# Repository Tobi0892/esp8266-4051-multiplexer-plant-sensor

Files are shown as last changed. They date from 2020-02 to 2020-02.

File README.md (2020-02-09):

# ESP8266 Multi Capacitive Soil Moisture Sensor

ESP8266 in combination with a eight port multiplexer to **support up to 8 capacitive soil moisture sensors**.

The esp8266 reads the sensors every 10 minutes, transfers the readings via MQTT to a broker and goes back to deep sleep. The MQTT messages and can be picked up by i.e. Home Assistant.

- Mode 1: USB powered
- Mode 2: Battery powered (optional solar)

The code is written in **MicroPython**.

## Mode 1: USB powered

### Parts required

- [Wemos D1 mini Pro V2.0.0 ESP8266](https://www.aliexpress.com/item/32724692514.html) 4,56€
- [Capacitive soil moisture sensor](https://www.aliexpress.com/item/32863717622.html) 0,61€
- [CD4051 Multiplexer](https://www.aliexpress.com/item/32424603555.html) 1,85€
- [Project box](https://www.aliexpress.com/item/4000392100897.html) 0,72€
- [Circuit board](https://www.aliexpress.com/item/1848518580.html) 1,66€
- [Wires](https://www.aliexpress.com/item/4000329909050.html) 1,90€
- [Pin headers](https://www.aliexpress.com/item/32861400498.html) 0,88€
- [3D printed sensor case](https://www.thingiverse.com/thing:2806217) (order print at [treatstock](https://www.treatstock.com/c/gregtu)) ~1,20€

A usb charger and micro usb cable is assumed to be available.

### Circuit diagram

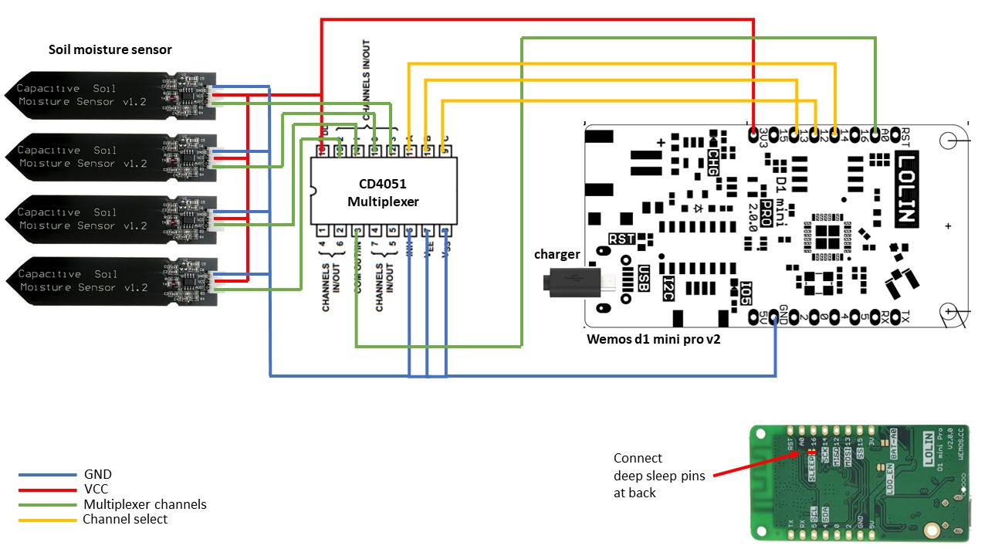
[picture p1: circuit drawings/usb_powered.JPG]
mode 1 wiring


## Mode 2: Battery powered

Use more batteries in parallel if you want (a) to decrease the time between sensor readings or (b) prolong the time until the next charging cycle or (c) compensate for smaller solar panels.

The solar panel is optional, of course you can also charge the batteries manually with a charger once they are drained. If you use a solar panel, you need to connect it via the micro usb port to the esp8266

Note: the Wemos D1 mini Pro v2.0.0 already has a built-in charging module. 

### Additional parts required

- [18650 3,7V 3400mAh battery](https://www.aliexpress.com/item/33016517000.html) 2,21€
- [JST connector](https://www.aliexpress.com/item/33027366342.html) 0,49€
- [Optinal 5V 5W solar panel](https://www.aliexpress.com/item/32952130996.html) 4,13€

### Circuit diagram

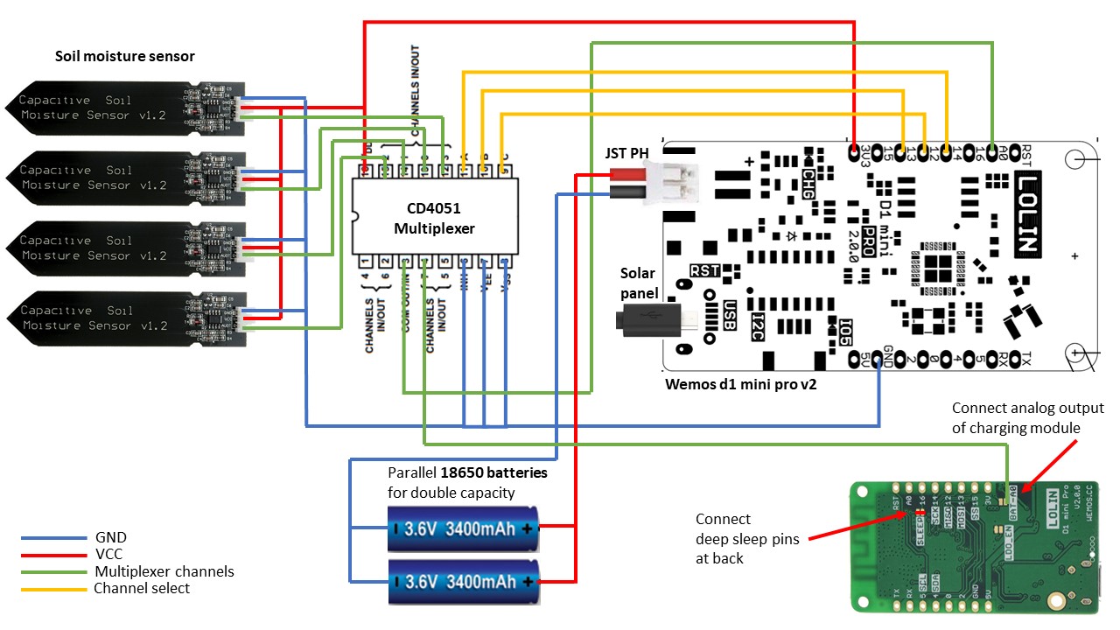
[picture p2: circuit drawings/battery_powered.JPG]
mode 2 wiring


## Setup

### Configuration

Use the `config.json` to configure the esp8266 (no changes in `boot.py` or `main.py` required).

```json
{
  "hostname": "NAME_OF_ESP8266",
  "wifi": {
    "ssid": "YOUR_WIFI_NAME",
    "password": "YOUR_WIFI_PASSWORD",
  },
  "mqtt": {
    "user": "MQTT_USER",
    "password": "MQTT_PASSWORD",
    "broker": "MQTT_BROKER_IP",
    "port": 1883,
    "topics": "TOPIC_NAME"
  }
}
```

### Flashing Code to ESP8266

I prefer PyCharm and the respective [MicroPython plugin](https://blog.jetbrains.com/pycharm/2018/01/micropython-plugin-for-pycharm/). Nevertheless, you can use any other suitable editor.

Create a configuration for each of the three files and flash them onto the esp8266. You can use the MicroPython REPL to watch the execution of the programs:

```
Connecting to WiFi...connected
Connecting to MQTT...connected
Sending: {"analog": "481", "percent": "7", "updated": "07.02.2020 23:12:25"} 
Going back to sleep...
```

### Home Assistant

Add i.e. two mqtt sensors to your `sensors.yaml` (your one esp8266 published to both topics as it operates multiple soil moisture sensors)

```yaml
- platform: mqtt
  name: "Ficus Benjamina"
  state_topic: "esp8266/pflanzen-wohnzimmer-fenster/sensor0"
  value_template: "{{ value_json.percent }}"
  unit_of_measurement: "%"
  json_attributes_topic: "esp8266/pflanzen-wohnzimmer-fenster/sensor0"
  icon: mdi:leaf
- platform: mqtt
  name: "Zitronenbaum"
  state_topic: "esp8266/pflanzen-wohnzimmer-fenster/sensor1"
  value_template: "{{ value_json.percent }}"
  unit_of_measurement: "%"
  json_attributes_topic: "esp8266/pflanzen-wohnzimmer-fenster/sensor1"
  icon: mdi:fruit-citrus
- platform: mqtt
  name: "Balsamapfel"
  state_topic: "esp8266/pflanzen-wohnzimmer-fenster/sensor2"
  value_template: "{{ value_json.percent }}"
  unit_of_measurement: "%"
  json_attributes_topic: "esp8266/pflanzen-wohnzimmer-fenster/sensor2"
  icon: mdi:sprout
```

And the following to `ui-lovelace.yaml` to display the two sensors in the lovelace frontend ([Custom multiple entities card is used in this example](https://github.com/benct/lovelace-multiple-entity-row))

```yaml
  - type: markdown
    style: !include /config/ui-lovelace/style/title.yaml
    content: Pflanzen

  - type: entities
    entities:
      - type: custom:multiple-entity-row
        entity: sensor.ficus_benjamina
        hide_state: true
        primary:
          entity: sensor.ficus_benjamina
          attribute: analog
          unit: ''
          name: 'Analog'
        secondary:
          entity: sensor.ficus_benjamina
          attribute: percent
          name: 'Wasser'
          unit: '%'
      - entity: sensor.zitronenbaum
        hide_state: true
        type: custom:multiple-entity-row
        primary:
          entity: sensor.zitronenbaum
          attribute: analog
          unit: ''
          name: 'Analog'
        secondary:
          entity: sensor.zitronenbaum
          attribute: percent
          unit: '%'
          name: 'Wasser'
      - entity: sensor.balsamapfel
        hide_state: true
        type: custom:multiple-entity-row
        primary:
          entity: sensor.balsamapfel
          attribute: analog
          unit: ''
          name: 'Analog'
        secondary:
          entity: sensor.balsamapfel
          attribute: percent
          unit: '%'
          name: 'Wasser'
```

Result in lovelace frontend:

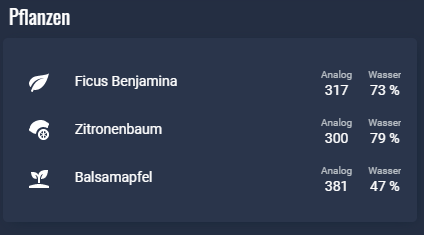
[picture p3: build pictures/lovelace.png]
lovelace


Detail view:

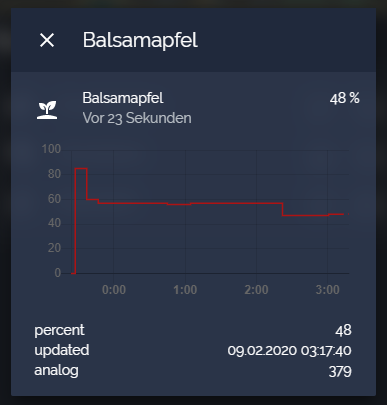
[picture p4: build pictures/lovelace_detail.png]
lovelace_details


## Schematics

- [Wemos D1 mini pro](https://wiki.wemos.cc/products:d1:d1_mini_pro)
- [CD4051 Multiplexer](http://www.ti.com/lit/ds/schs047i/schs047i.pdf)

## Build pictures
Two sensors placed in a plant each
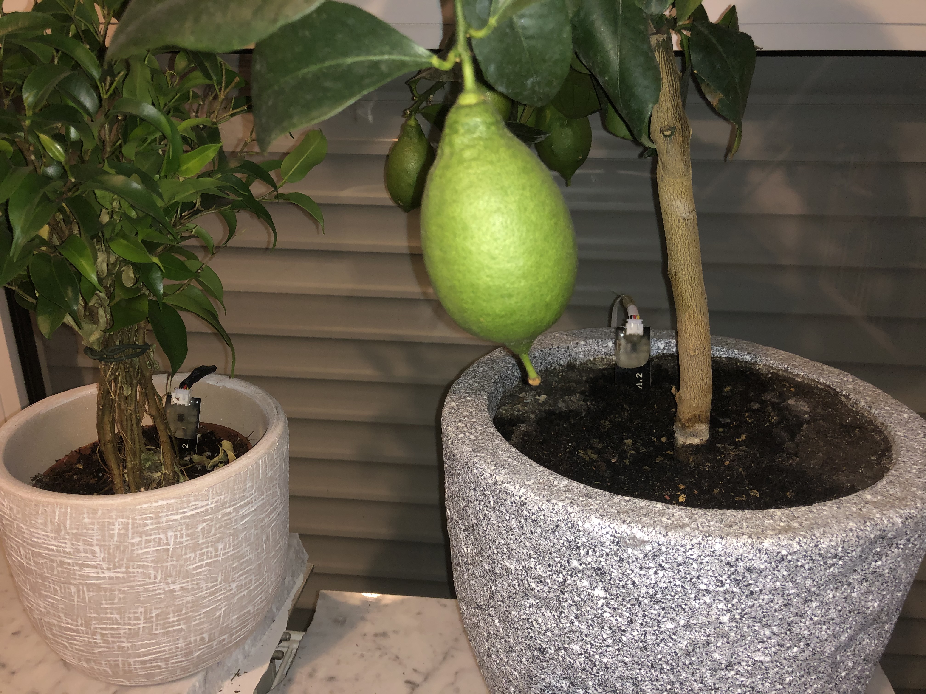
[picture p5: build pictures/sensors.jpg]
sensors


Indoor case ([source](https://www.thingiverse.com/thing:2806217))
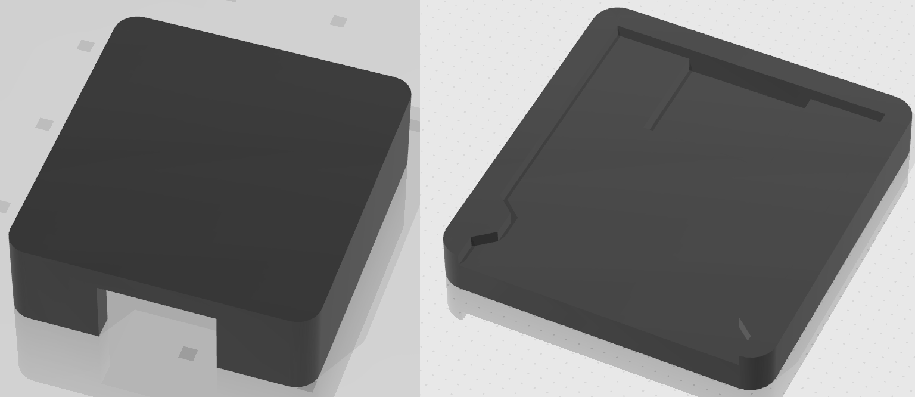
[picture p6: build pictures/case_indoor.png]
indoor_case


Outdoor case with top cover ([source](https://www.thingiverse.com/thing:3625073))
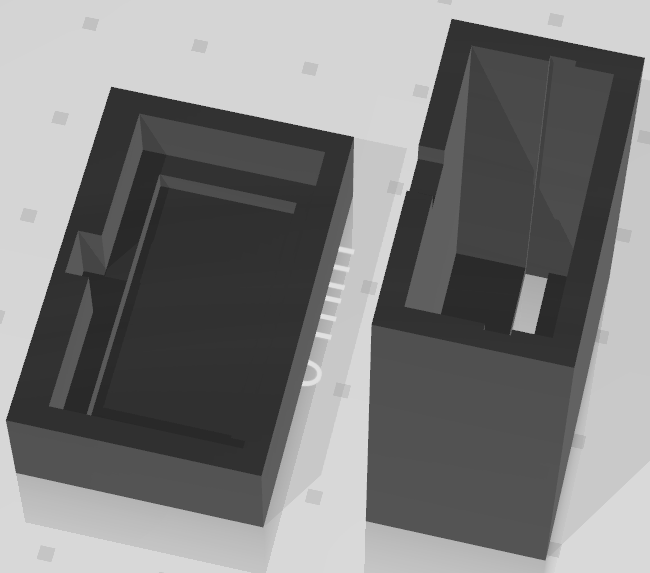
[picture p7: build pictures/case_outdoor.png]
outdoor_case


Three sensors connected to the esp (3 more available - multiplexer supports up to 8)
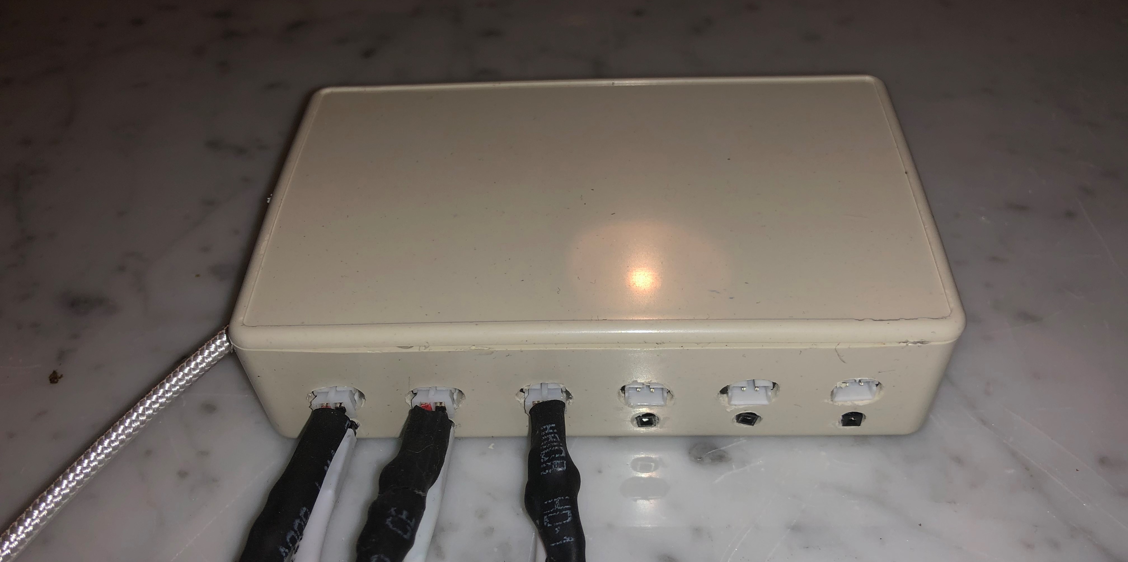
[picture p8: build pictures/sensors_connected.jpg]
sensors_connected


Front view of the connectors (the wholes could have been drilled better)
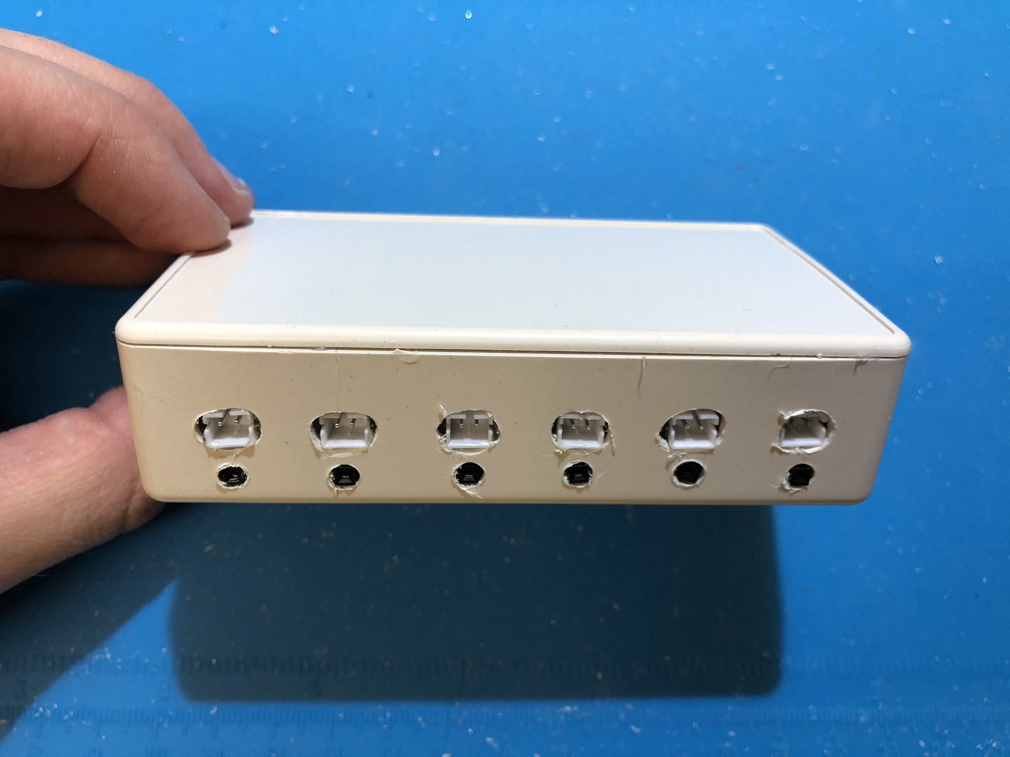
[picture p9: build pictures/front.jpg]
front


Micro usb power connected
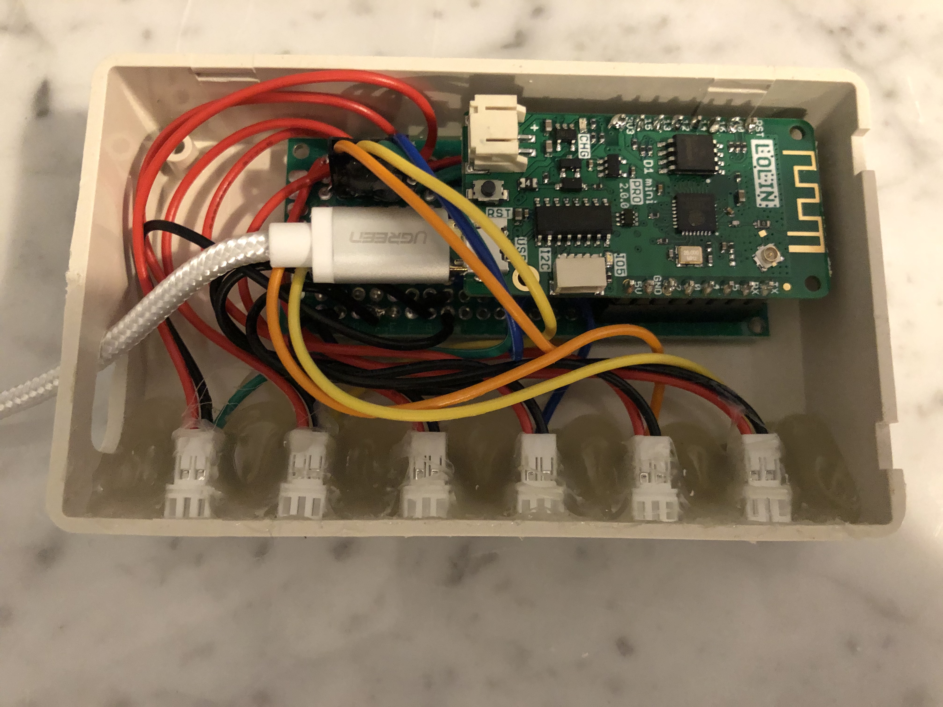
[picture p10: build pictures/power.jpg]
power


VCC and GND JST connectors glued in place
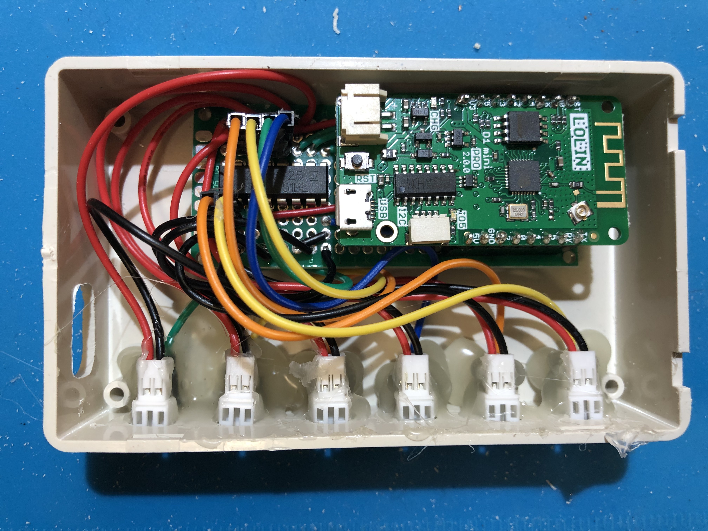
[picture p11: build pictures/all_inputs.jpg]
all_inputs


6 analog pins (multiplexer channels) for 6 soil moisture sensors glued in place
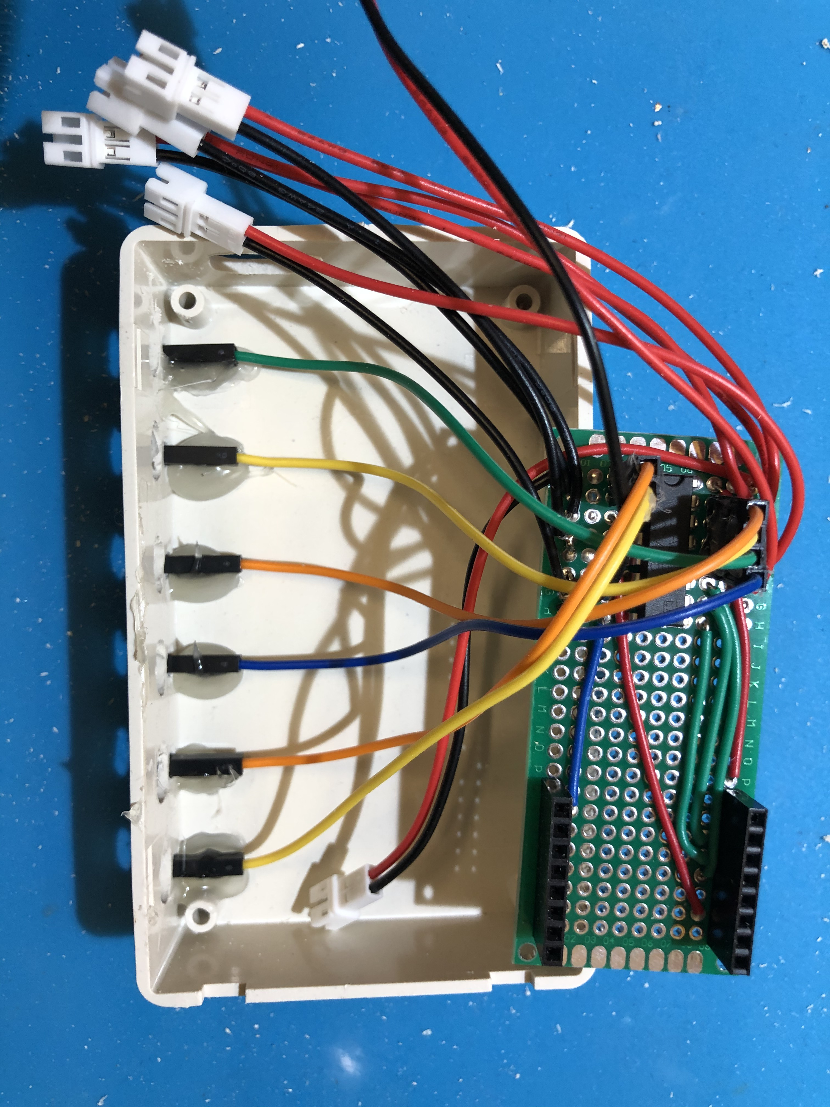
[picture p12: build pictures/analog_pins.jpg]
analog pins


Case prepared
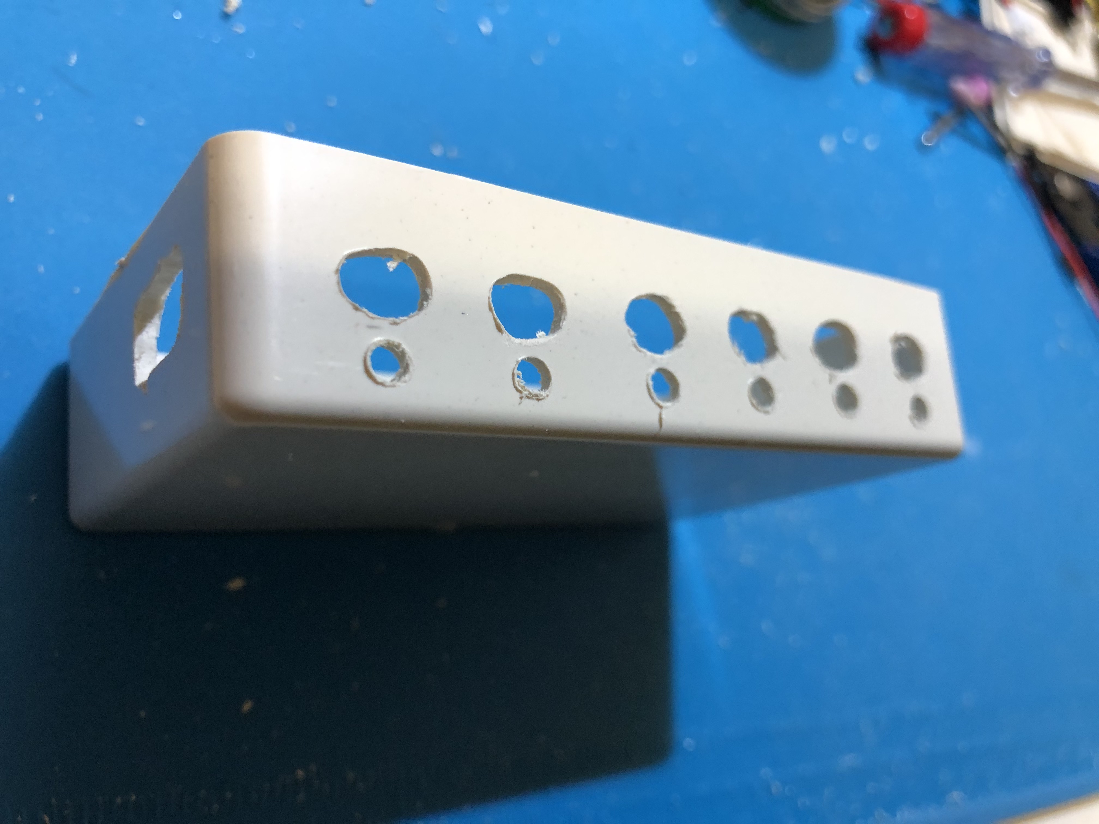
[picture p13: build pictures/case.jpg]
Case


Mode 1 completed without case and ability to connect 4 moisture sensors (2 more have been added after taking the picture)
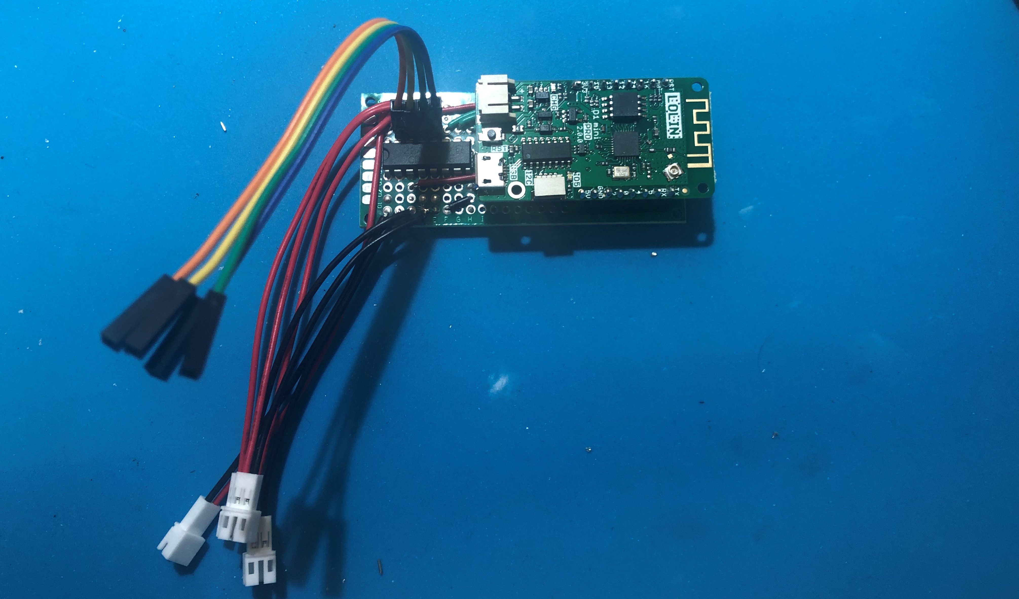
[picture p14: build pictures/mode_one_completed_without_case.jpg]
Mode one completed without case


Sleep pin soldered to be able to wake up from deep sleep
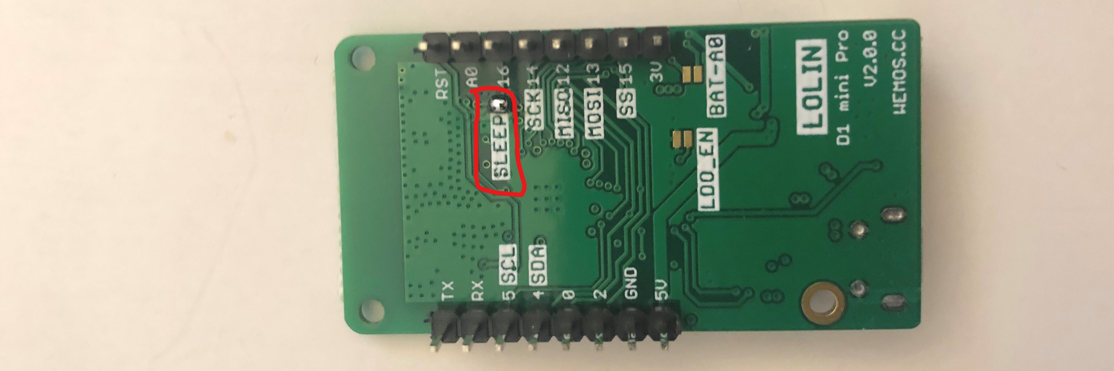
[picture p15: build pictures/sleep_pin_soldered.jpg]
Sleep Pin soldered


Wiring below esp8266 (not all connections are visible from the top)
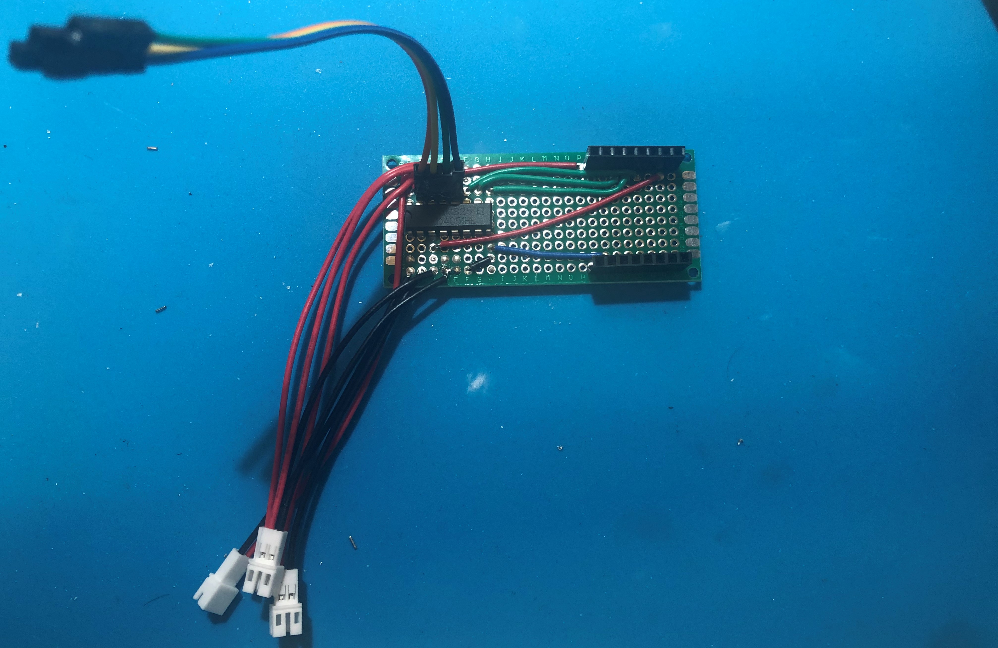
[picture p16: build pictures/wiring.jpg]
Wiring


Back with soldered connections
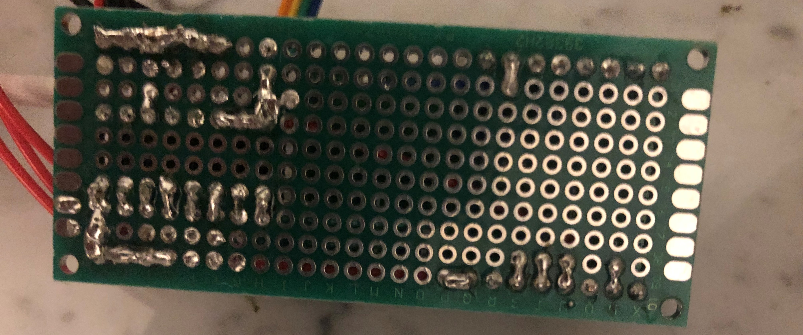
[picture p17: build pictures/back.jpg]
Back


Multiplexer wired to headers for esp8266 without connectors for sensors
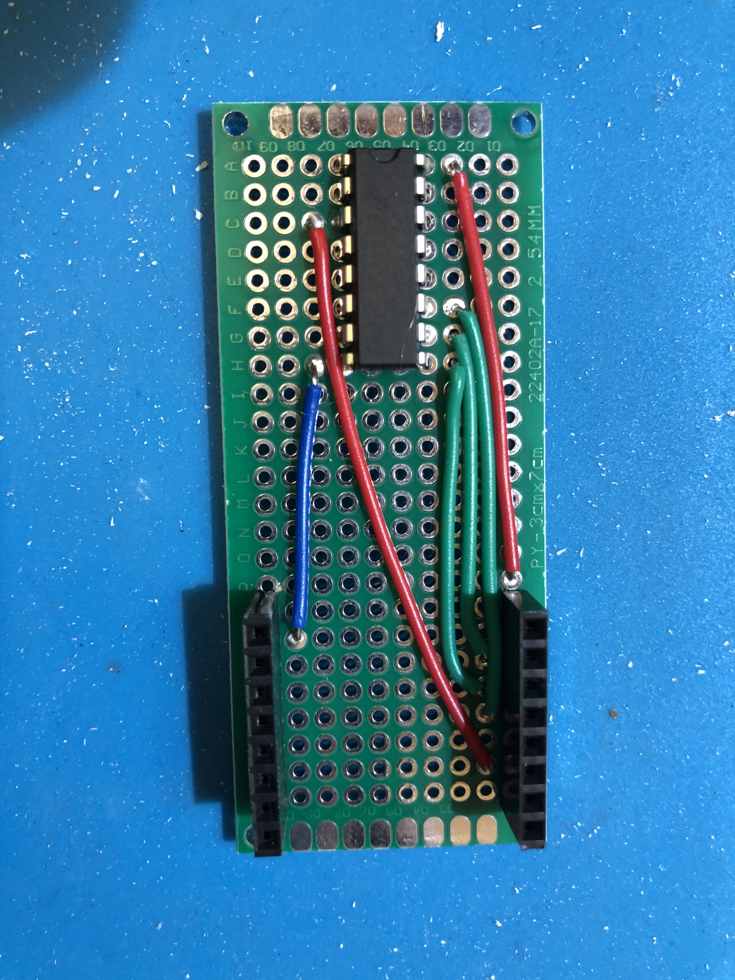
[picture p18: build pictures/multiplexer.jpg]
multiplexer


Back of esp8266 and multiplexer wiring
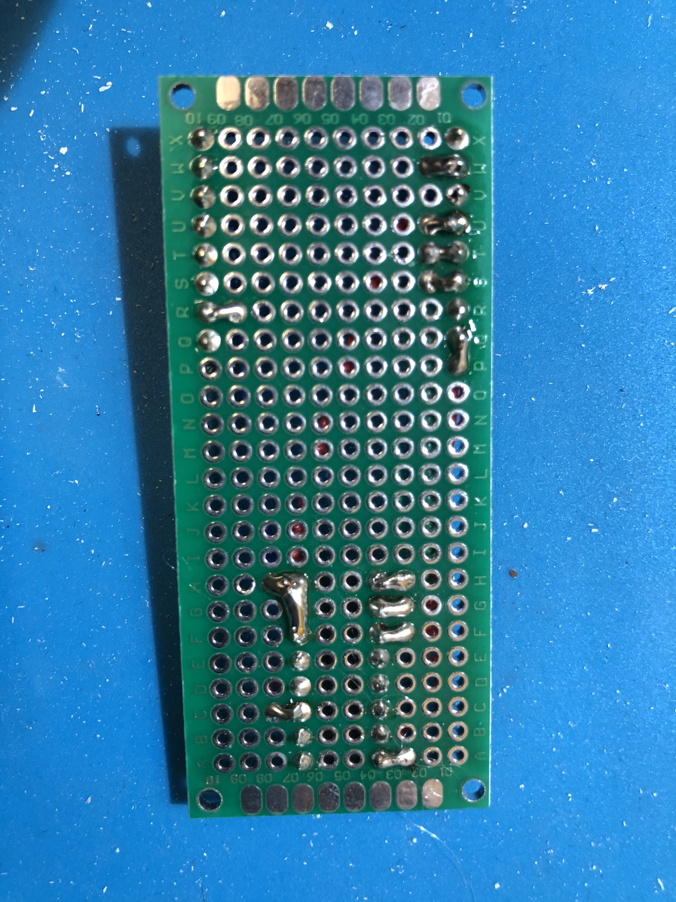
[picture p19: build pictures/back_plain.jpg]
back_plain


Capacitive soil moisture sensors protected with hot glue
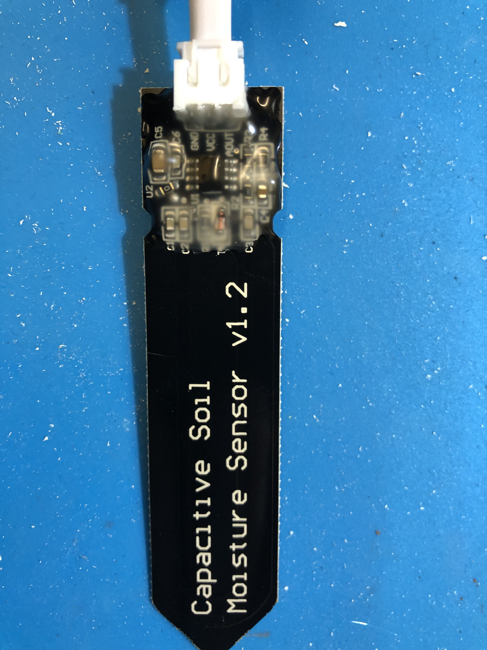
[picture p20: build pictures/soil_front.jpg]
soil front


Also pins at back are protected 
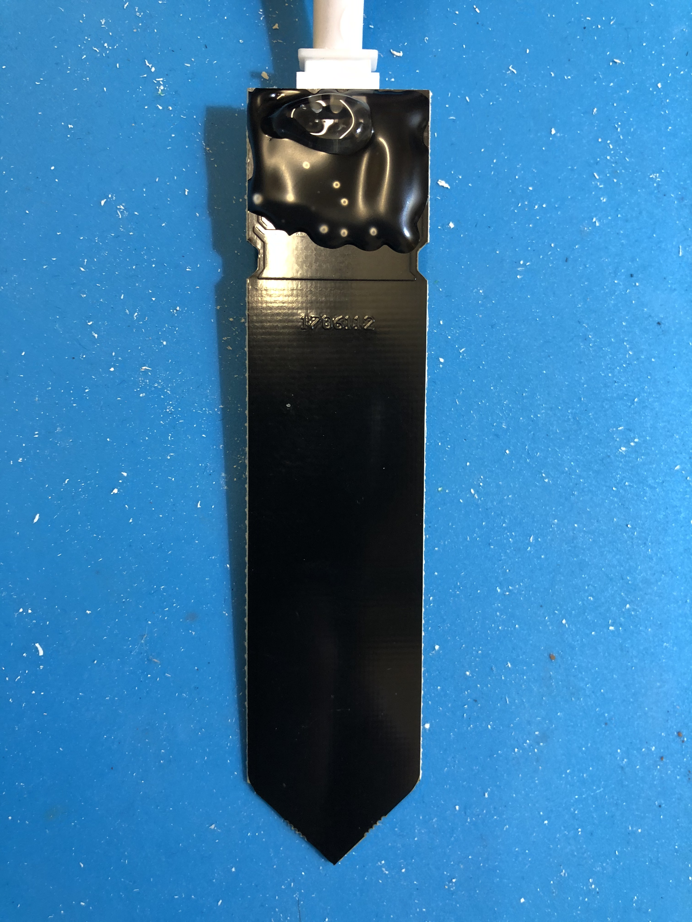
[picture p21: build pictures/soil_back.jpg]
soil_back


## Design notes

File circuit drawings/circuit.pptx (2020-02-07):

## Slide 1

Soil moisture sensor

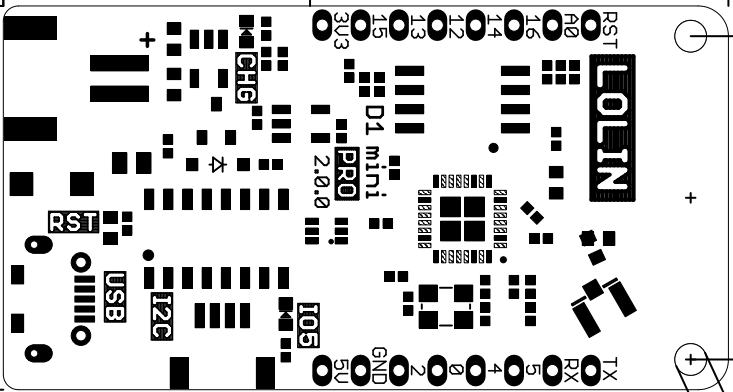
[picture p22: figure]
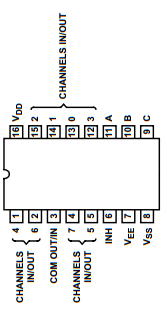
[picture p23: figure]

CD4051
Multiplexer

charger

Wemos d1 mini pro v2

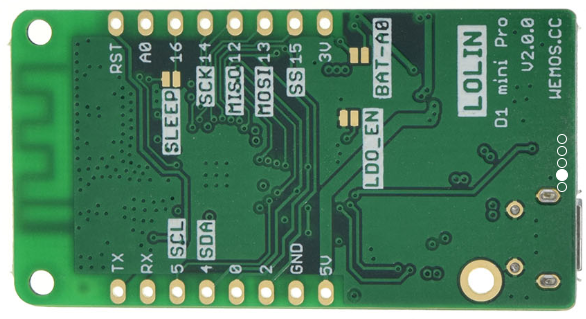
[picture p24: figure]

GND

Connect
deep sleep pins
at back

Channel select

Multiplexer channels

VCC

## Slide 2

Soil moisture sensor

CD4051
Multiplexer

JST PH

Solar
panel

Wemos d1 mini pro v2

Connect analog output
of charging module

Parallel 18650 batteries for double capacity

GND

Connect
deep sleep pins
at back

Channel select

Multiplexer channels

VCC

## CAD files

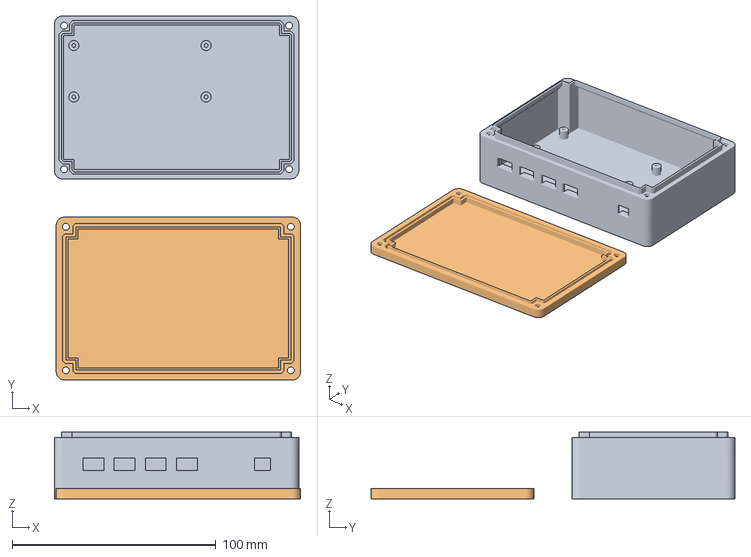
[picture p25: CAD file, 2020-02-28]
3D printable cases/controller indoor/CE5_case.3mf
120.9 x 178.8 x 32.7 mm

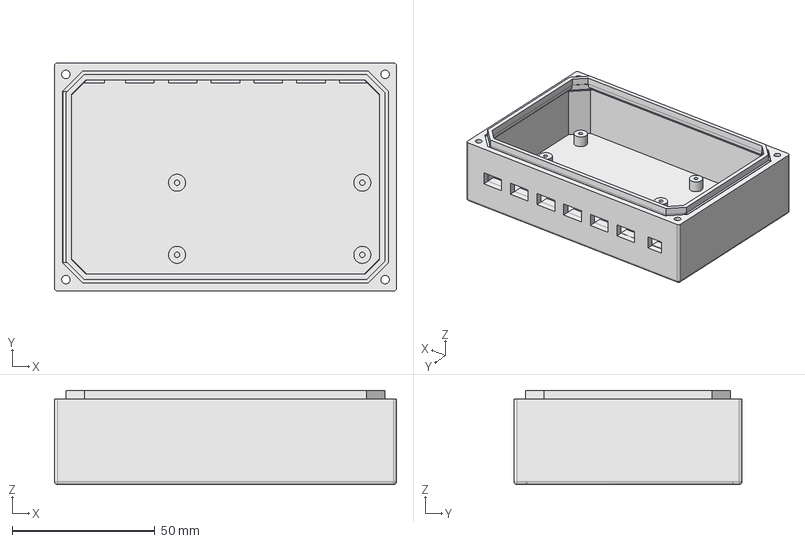
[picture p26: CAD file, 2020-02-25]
3D printable cases/controller indoor/FreeCAD/case bottom.FCStd
120.0 x 80.0 x 33.0 mm

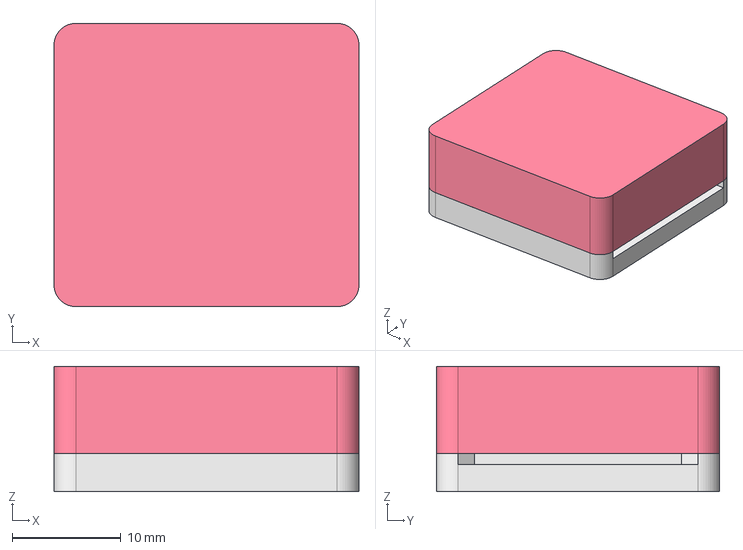
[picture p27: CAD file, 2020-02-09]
3D printable cases/sensor indoor/moist.fcstd
28.0 x 26.0 x 11.5 mm

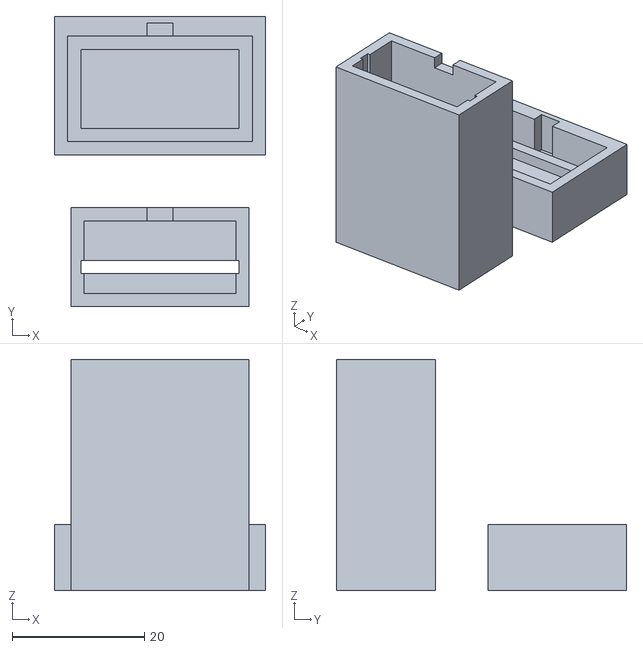
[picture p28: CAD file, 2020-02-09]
3D printable cases/sensor outdoor/soil.stl
32.0 x 44.0 x 35.0

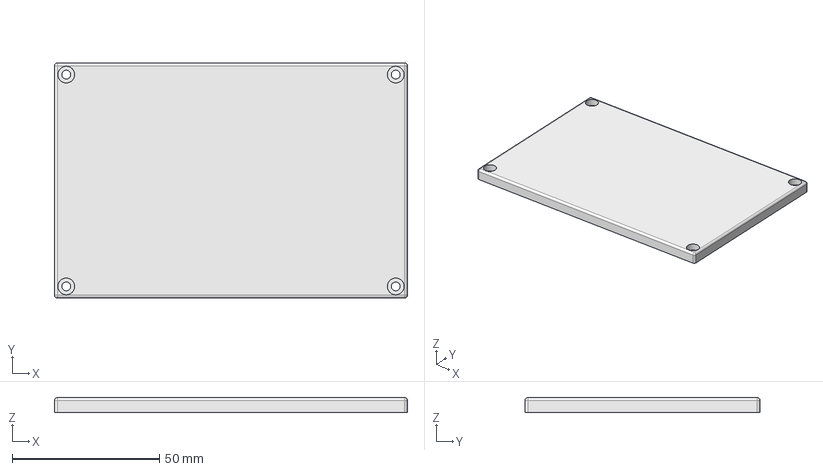
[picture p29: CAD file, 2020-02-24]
3D printable cases/controller indoor/FreeCAD/case top.FCStd
120.0 x 80.0 x 5.00 mm

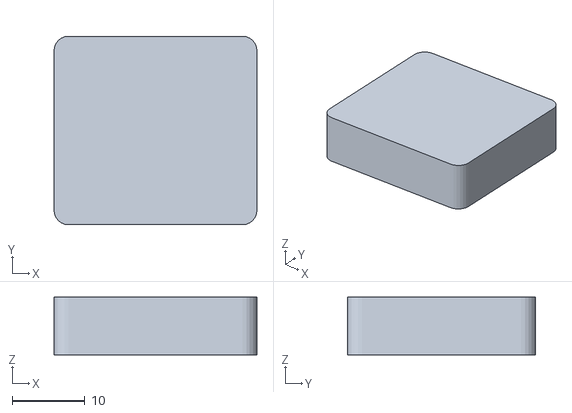
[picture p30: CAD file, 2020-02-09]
3D printable cases/sensor indoor/moist-oberteil.stl
28.0 x 26.0 x 8.00

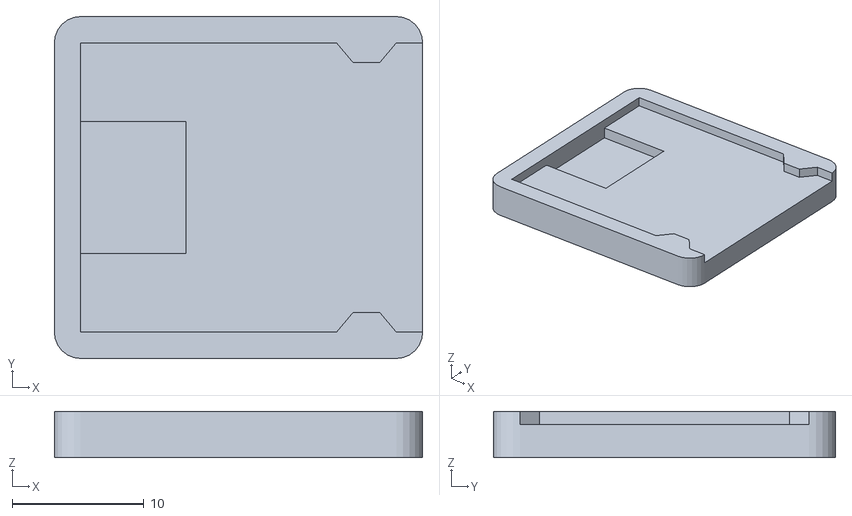
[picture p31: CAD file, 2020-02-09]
3D printable cases/sensor indoor/moist-unterteil.stl
28.0 x 26.0 x 3.50

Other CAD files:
3D printable cases/controller indoor/Box Innen v14.f3d
3D printable cases/controller indoor/Box Raw v26.f3d
3D printable cases/controller indoor/case bottom.stl
3D printable cases/controller indoor/case top.stl

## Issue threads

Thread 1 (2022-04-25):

Sensors still alive?

auchri, 2022-04-25:
Hi @Tobi0892,

thank you for the detailed documentation of your great project!

I've done something similar last year using the same moisture sensors as you and my sensors completely corroded after been just a few weeks in the soil.

Did you experience something similar?

One solution I found on the internet to this problem is to connect the VCC pin of the sensors to a digital output pin of the esp8266 (and maybe use a second multiplexer to power only the desired sensor).

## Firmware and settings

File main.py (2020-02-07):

from json import load, dumps
from time import sleep

from machine import Pin, ADC, RTC, deepsleep, DEEPSLEEP
from umqtt.simple import MQTTClient

with open("config.json", "r") as config:
    config = load(config)

adc = ADC(0)

pinA = Pin(12, Pin.OUT)
pinB = Pin(13, Pin.OUT)
pinC = Pin(14, Pin.OUT)


def setMultiplexerPins(a, b, c):
    pinA.value(a)
    pinB.value(b)
    pinC.value(c)


def readSensors():

    sensors = {}

    i = 0
    while i < 8:
        # Convert sensor number to binary in order to set sensor input of multiplexer
        args = list("{0:03b}".format(i))
        setMultiplexerPins(int(args[0]), int(args[1]), int(args[2]))

        # Read sensor value
        sensorAnalog = adc.read()
        if sensorAnalog >= 50:
            wetPlant = 250 # water 200
            dryPlant = 500 # air 700
            sensorPercent = int((1 - (sensorAnalog - wetPlant) / (dryPlant - wetPlant)) * 100)

            if sensorPercent > 100:
                sensorPercent = 100
            elif sensorPercent < 0:
                sensorPercent = 0

            updated = RTC().datetime()

            sensors["sensor" + str(i)] = {
                "analog": sensorAnalog,
                "percent": sensorPercent,
                "updated": "{:02d}.{:02d}.{:02d} {:02d}:{:02d}:{:02d}".format(updated[2], updated[1], updated[0], int(updated[4]) + 1, updated[5], updated[6])
            }

        i += 1

    return sensors


def connectMQTT():
    print("Connecting to MQTT...", end="")

    mqtt = MQTTClient(
        config["hostname"],
        config["mqtt"]["broker"],
        user=config["mqtt"]["user"],
        password=config["mqtt"]["password"],
        port=config["mqtt"]["port"]
    )

    mqtt.connect()
    print("connected")
    return mqtt


###### MAIN ######

# Read sensors
sensors = readSensors()

# Send result via mqtt
mqtt = connectMQTT()

for sensor, data in sensors.items():
    print("Sending: " + dumps(data))
    mqtt.publish(
        config["mqtt"]["topics"] + "/" + config["hostname"] + "/" + sensor,
        dumps(data)
    )

# Wait for message(s) to be published
sleep(3)
mqtt.disconnect()

# Enter next cycle for 10 minutes deep sleep
print("Going back to sleep...")
rtc = RTC()
rtc.irq(trigger=rtc.ALARM0, wake=DEEPSLEEP)
rtc.alarm(rtc.ALARM0, 600000)
deepsleep()

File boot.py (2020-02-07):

import gc
import json
from time import sleep
from ntptime import settime

import esp
import network
from machine import reset

esp.osdebug(None)
gc.collect()

with open("config.json", "r") as config:
    config = json.load(config)


def connectWifi():
    wifi = network.WLAN(network.STA_IF)
    print("")
    print("Connecting to WiFi...", end="")

    wifi.config(
        essid=config["hostname"],
        dhcp_hostname=config["hostname"]
    )

    wifi.active(True)

    wifi.connect(
        config["wifi"]["ssid"],
        config["wifi"]["password"]
    )

    while not wifi.isconnected():
        pass

    print("connected")


try:
    connectWifi()
    settime()

except(RuntimeError, TypeError, NameError):
    sleep(60)
    reset()

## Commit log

2020-02-03 initial reading of a sensor via a multiplexer
2020-02-03 reading all sensor slots of the multiplexer and returning the result in json
2020-02-04 send sensor data via mqtt to a broker
    [boot.py, main.py]
2020-02-07 Deepsleep, wait for publish, tolerance for disconnected sensors increased
    For deepsleep pin 16 must be soldered
    [main.py]
2020-02-07 circuit drawings
2020-02-09 3D sensor covers added
    [moist-oberteil.stl, moist-unterteil.stl, moist.fcstd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]
2020-02-22 3d files added
    [CE5_case.3mf, case bottom.FCStd, case bottom.stl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]
2020-02-24 screw head diameter adjusted
    [CE5_case.3mf, case top.FCStd, case top.stl]
2020-02-25 updated pcb holders
    [case bottom.FCStd, case bottom.stl]
2020-02-28 Box modeled with Fusion 360
    [Box Innen v14.f3d, Box Raw v26.f3d, CE5_case.3mf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]
2020-02-28 Cura project file added
    [CE5_case.3mf]
2020-02-28 Cura project file updated
    [CE5_case.3mf]
